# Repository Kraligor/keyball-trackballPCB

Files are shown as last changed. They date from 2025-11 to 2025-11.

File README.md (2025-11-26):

# Fork Info

This fork includes reverse-engineered KiCAD files and BOM for the trackball PCB. Resistors and caps are 0603/1608, connector is 2.54. The connector layout and component values are identical to the the original PCB, footprints differ as it's supposed to be hand-soldered, so the packages are bigger.

# Keyball Series

Keyball61

Keyball series is keyboard family which have 100% track ball.

Keyboards in the family are:

* Available
    * Keyball39: split + 39 keys + a track ball
    * Keyball44: split + 44 keys + a track ball
    * Keyball61: split + 61 keys + a track ball
* Unavailable
    * Keyball46 (first one!)
    * One47

## Where to Buy

|Keyboard |Yushakobo / 遊舎工房 |Shirogane Lab / 白金ラボ |
|---|---|---|
|Keyball39  |<https://shop.yushakobo.jp/products/5357>  |<https://shirogane-lab.net/items/64b8f8693ee3fd0045280190> |
|Keyball44  |<https://shop.yushakobo.jp/products/8337>  |<https://shirogane-lab.net/items/64b7a006eb6dbe00346cd0c5> |
|Keyball61  |<https://shop.yushakobo.jp/products/5358>  |<https://shirogane-lab.net/items/64b8ed191435c1002bc4cd30> |

## Build Guide

*   Keyball39:
    [English/英語](/keyball39/doc/rev1/buildguide_en.md),
    [日本語/Japanese (ピンヘッダ版)](./keyball39/doc/rev1/buildguide_jp.md),
    [日本語/Japanese (コンスルー版)](./keyball39/doc/rev1/buildguide_jp_conth.md)
*   Keyball44: ~~English/英語~~ (Sorry, unavailable),
    [日本語/Japanese (ピンヘッダ版)](./keyball44/doc/rev1/buildguide_jp.md),
    [日本語/Japanese (コンスルー版)](./keyball44/doc/rev1/buildguide_jp_conth.md)
*   Keyball46:
    [English/英語](./keyball46/doc/rev1/buildguide_en.md),
    [日本語/Japanese](./keyball46/doc/rev1/buildguide_jp.md)
*   Keyball61:
    [English/英語](./keyball61/doc/rev1/buildguide_en.md),
    [日本語/Japanese (ピンヘッダ版)](./keyball61/doc/rev1/buildguide_jp.md),
    [日本語/Japanese (コンスルー版)](./keyball61/doc/rev1/buildguide_jp_conth.md)

## Firmware

See [document for firmware source code](./qmk_firmware/keyboards/keyball/readme.md).

### Pre-compiled Firmwares

(TO BE DOCUMENTED)

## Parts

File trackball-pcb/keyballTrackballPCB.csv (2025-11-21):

Reference | Qty | Value | DNP | Exclude from BOM | Exclude from Board | Footprint | Datasheet
C1,C4,C5 | 3 | 10uF |  |  |  | Capacitor_SMD:C_0603_1608Metric_Pad1.08x0.95mm_HandSolder | ~
C2,C3,C6,C7 | 4 | 100nF |  |  |  | Capacitor_SMD:C_0603_1608Metric_Pad1.08x0.95mm_HandSolder | ~
J1 | 1 | Conn_01x07 |  |  |  | Connector_PinHeader_2.54mm:PinHeader_1x07_P2.54mm_Vertical | ~
J2 | 1 | Conn_01x01 |  |  |  | Connector_PinHeader_2.54mm:PinHeader_1x01_P2.54mm_Vertical | ~
R1 | 1 | 37.4k |  |  |  | Resistor_SMD:R_0603_1608Metric_Pad0.98x0.95mm_HandSolder | ~
R2 | 1 | 63.4k |  |  |  | Resistor_SMD:R_0603_1608Metric_Pad0.98x0.95mm_HandSolder | ~
R3,R5,R7,R11 | 4 | 0 |  |  |  | Resistor_SMD:R_0603_1608Metric_Pad0.98x0.95mm_HandSolder | ~
R4,R6,R10 | 3 | 10k |  |  |  | Resistor_SMD:R_0603_1608Metric_Pad0.98x0.95mm_HandSolder | ~
R8 | 1 | 39 |  |  |  | Resistor_SMD:R_0603_1608Metric_Pad0.98x0.95mm_HandSolder | ~
R9 | 1 | 1M_DNI |  |  |  | Resistor_SMD:R_0603_1608Metric_Pad0.98x0.95mm_HandSolder | ~
U1 | 1 | TPS73601DBV |  |  |  | Package_TO_SOT_SMD:SOT-23-5 | http://www.ti.com/lit/ds/symlink/tps736.pdf
U2,U3 | 2 | TXS0102DCU |  |  |  | Package_SO:VSSOP-8_2.3x2mm_P0.5mm | http://www.ti.com/lit/gpn/txs0102
U4 | 1 | PMW3360DM-T2QU |  |  |  | Pixart:PMW3360DM-T2QU | https://www.pixart.com/_getfs.php?tb=product&id=10&fs=ck2_fs_en

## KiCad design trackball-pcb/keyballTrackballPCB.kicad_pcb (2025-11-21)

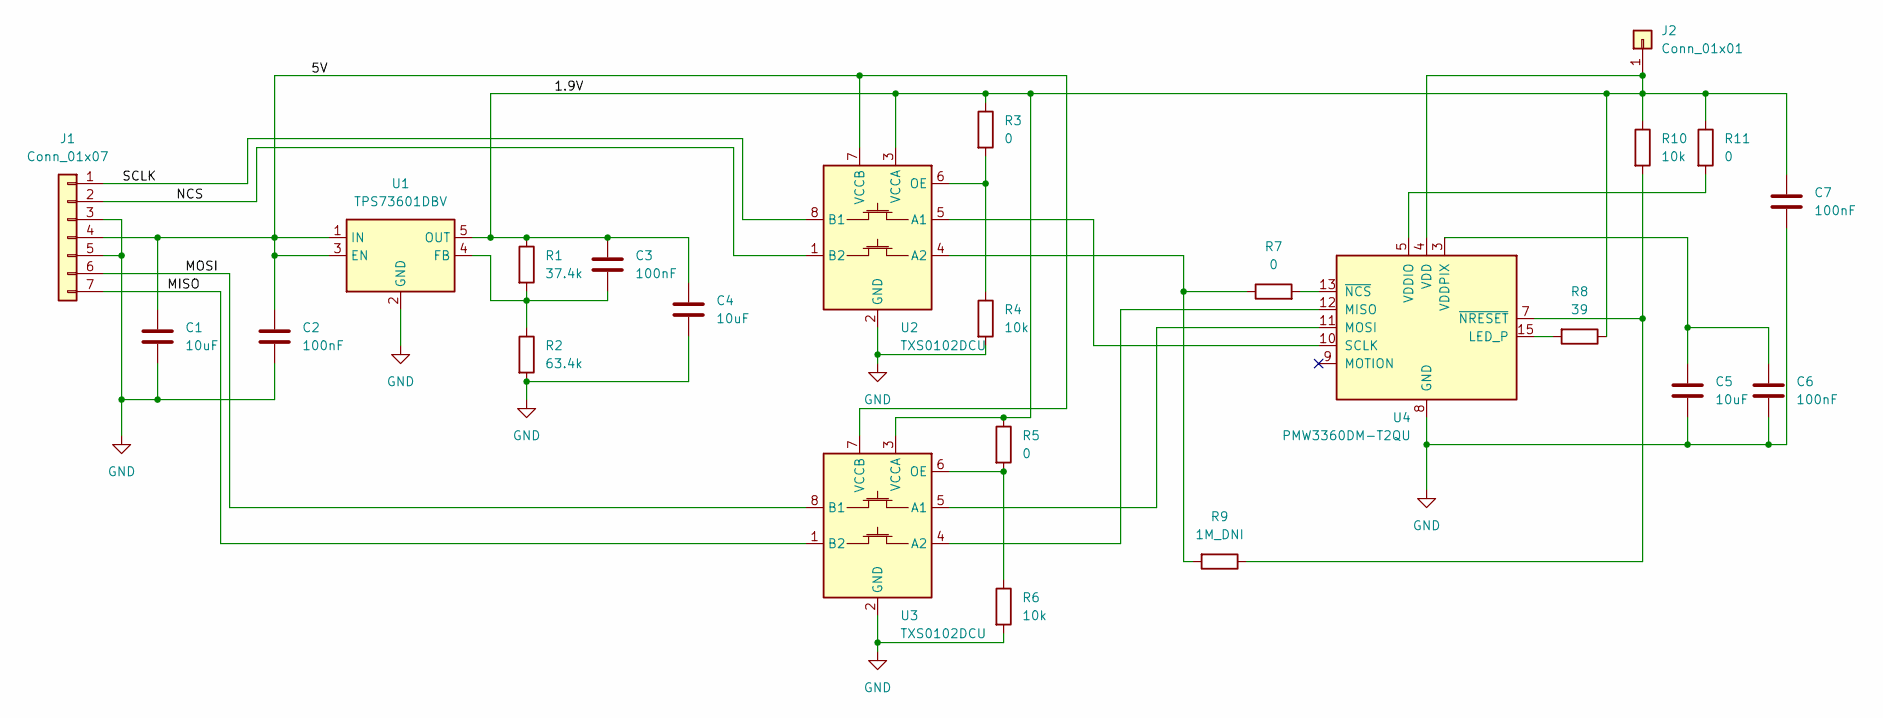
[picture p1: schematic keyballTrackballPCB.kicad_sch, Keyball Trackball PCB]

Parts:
C1, C4, C5: 10uF; C_0603_1608Metric_Pad1.08x0.95mm_HandSolder
C2, C3, C6, C7: 100nF; C_0603_1608Metric_Pad1.08x0.95mm_HandSolder
J1: Conn_01x07; PinHeader_1x07_P2.54mm_Vertical
J2: Conn_01x01; PinHeader_1x01_P2.54mm_Vertical
R1: 37.4k; R_0603_1608Metric_Pad0.98x0.95mm_HandSolder
R2: 63.4k; R_0603_1608Metric_Pad0.98x0.95mm_HandSolder
R3, R5, R7, R11: 0; R_0603_1608Metric_Pad0.98x0.95mm_HandSolder
R4, R6, R10: 10k; R_0603_1608Metric_Pad0.98x0.95mm_HandSolder
R8: 39; R_0603_1608Metric_Pad0.98x0.95mm_HandSolder
R9: 1M_DNI; R_0603_1608Metric_Pad0.98x0.95mm_HandSolder
U1: TPS73601DBV; SOT-23-5
U2, U3: TXS0102DCU; VSSOP-8_2.3x2mm_P0.5mm
U4: PMW3360DM-T2QU

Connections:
/1.9V: C3.1, C4.1, C7.1, J2.1, R1.1, R3.1, R5.1, R8.1, R10.1, R11.1, U1.5 (OUT), U2.3 (VCCA), U3.3 (VCCA), U4.4 (VDD)
/5V: C1.1, C2.1, J1.4, U1.1 (IN), U1.3 (EN), U2.7 (VCCB), U3.7 (VCCB)
/MISO: J1.7, U3.1 (B2)
/MOSI: J1.6, U3.8 (B1)
/NCS: J1.2, U2.1 (B2)
/SCLK: J1.1, U2.8 (B1)
GND: C1.2, C2.2, C4.2, C5.2, C6.2, C7.2, J1.3, J1.5, R2.2, R4.2, R6.2, U1.2 (GND), U2.2 (GND), U3.2 (GND), U4.8 (GND)
unnamed: C3.2, R1.2, R2.1, U1.4 (FB)
unnamed: U2.5 (A1), U4.10 (SCLK)
unnamed: R7.1, R9.2, U2.4 (A2)
unnamed: R3.2, R4.1, U2.6 (OE)
unnamed: U3.5 (A1), U4.11 (MOSI)
unnamed: U3.4 (A2), U4.12 (MISO)
unnamed: R5.2, R6.1, U3.6 (OE)
unnamed: R8.2, U4.15 (LED_P)
unnamed: R11.2, U4.5 (VDDIO)
unnamed: C5.1, C6.1, U4.3 (VDDPIX)
unnamed: R7.2, U4.13 (~NCS)
unnamed: R9.1, R10.2, U4.7 (~NRESET)

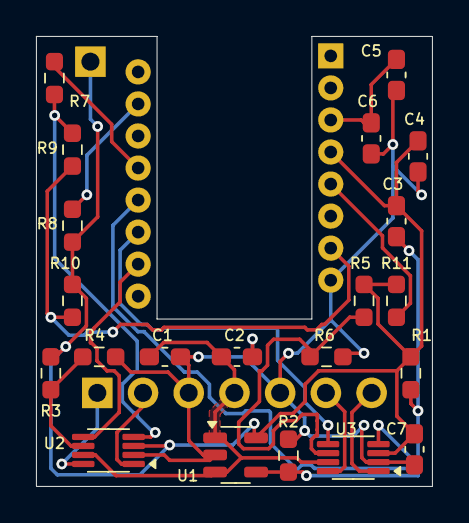
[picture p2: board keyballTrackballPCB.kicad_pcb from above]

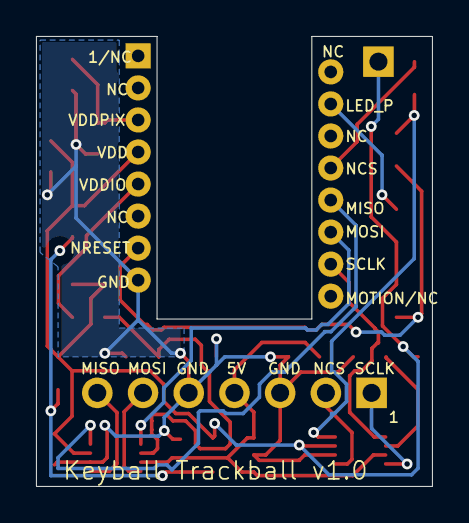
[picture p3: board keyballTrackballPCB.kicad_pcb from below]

Board: 2 copper layers, 22.0 x 25.0 mm, 24 parts (3 on the bottom side), 19 nets.

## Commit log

2025-11-21 Uploading KiCAD files
    [keyballTrackballPCB-B_Cu.gbr, keyballTrackballPCB-B_Mask.gbr, keyballTrackballPCB-B_Silkscreen.gbr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]
2025-11-21 add BOM
    [keyballTrackballPCB.csv]
